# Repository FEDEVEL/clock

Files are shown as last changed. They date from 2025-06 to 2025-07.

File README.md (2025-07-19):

# DESIGN AND BUILD THIS CLOCK BY YOURSELF
Watch a full step-by-step tutorial about how you can build this clock by yourself here: https://youtu.be/bcvq30J4SnQ

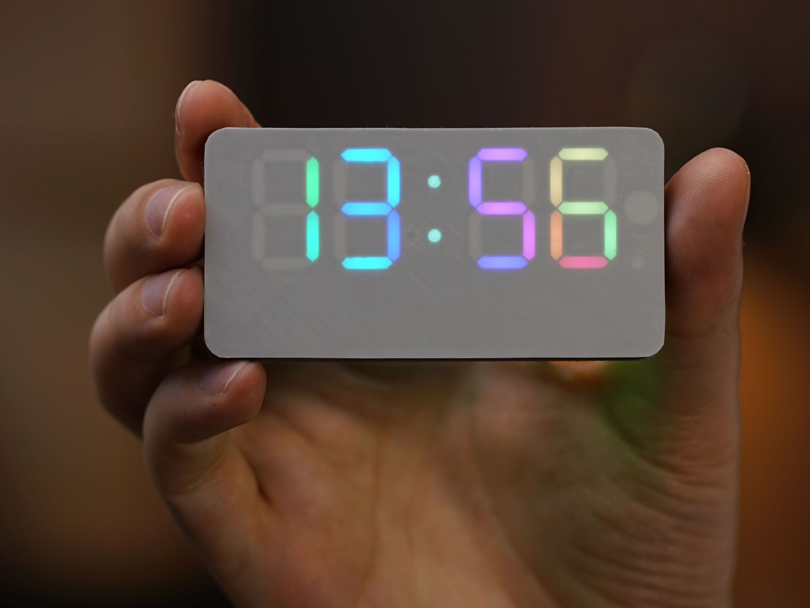
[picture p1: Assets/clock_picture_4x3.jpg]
Clock


# About this Clock Project
I created this clock for everyone who is interested in electronics. Even if you have never designed any electronics before, by following this step-by-step youtube tutorial you will design and manufacture this clock.

Watch and follow the tutorial here: https://youtu.be/bcvq30J4SnQ

# Clock Description
This is a nice clock with big segments and you can set color and intesity of each segment. There are three buttons, buzzer, light sensor and RTC with battery backup. The clock is powered through USB C and has features such current time, timer and stopwatch. Feel free to add your own features!

Why I designed this clock?
- it's a very simple project, so it was fun
- I often need a clock with big display and the right color and intensity when checking time in the middle of the night without my glasses on
- I often need a simple timer or stopwatch for example when cooking

# What is in this github repository
You will find here all the files you need to build this clock.

# Schematic and PCB
If you just would like to open and have a look at the Schematic and PCB, you can do it directly in your browser, here: https://oshwlab.com/robertferanec/clock/

# User Manual (How to use this clock)
The clock has three modes: Clock, Stopwatch and Timer. To switch between the modes press the buttons. The clock has battery backed RTC to keep the time always accurate. A simple web interface can be used to change default settings. I will write more detialed manual if there is interest. 

# License
Clock © 2025 by FEDEVEL is licensed under [Creative Commons Attribution-NonCommercial-ShareAlike 4.0 International](https://creativecommons.org/licenses/by-nc-sa/4.0/?ref=chooser-v1). For commercial use, contact me at info@fedevel.com

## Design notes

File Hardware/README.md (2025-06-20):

# What is here
- EasyEDA source file with Schematic and PCB (this file can be imported to EasyEDA PRO software)
- All the files needed to manufacture and build the clock (inside of Manufacturing directory)

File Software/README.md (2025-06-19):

# What is here
- Circuitpython (file adafruit-circuitpython-raspberry_pi_pico-en_US-9.2.7.uf2)
- Clock firmware source files (inside of RP2040 Files)
- Clock configuration website (RP2040 Files/clock_setup.html)

# To flash the firmware
## Flash this first - Circuitpython
Connect the board to USB and quickly press Reset button twice. The board will appear as RPI-RP2 storage. Copy adafruit-circuitpython-raspberry_pi_pico-en_US-9.2.7.uf2 file there. You need to do this only once.

## Updating the clock firmware
Before this, you need to have Circuitpython running on the clock board already (see the previous step). To update the clock software, folow these steps:
1. Hold USR1 button down and connect the board to USB
1. The board will be mounted as CIRCUITPY storage
1. Copy all the files from RP2040 Files directory to CIRCUITPY storage

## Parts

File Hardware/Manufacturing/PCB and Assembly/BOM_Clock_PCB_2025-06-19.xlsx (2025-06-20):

No. | Quantity | Comment | Designator | Footprint | Value | Manufacturer Part | Manufacturer | Supplier Part | Supplier | Layer
1 | 1 | 2.7kHz | BUZZER1 | BUZ-TH_BD9.0-P4.00-D0.6-FD | 2.7kHz | QMB-09B-03 | 华能 | C96256 | LCSC | B
2 | 4 | 2.2uF | C101,C105,C106,C107 | C0402 | 2.2uF | CL05A225MQ5NSNC | SAMSUNG(三星) | C12530 | LCSC | B
3 | 48 | 100nF | C102,C103,C104,C108,C109,C113,C114,C115,C116,C125,C126,C127,C210,C211,C212,C213,C214,C215,C216,C217,C218,C219,C220,C221,C222,C223,C224,C225,C226,C227,C228,C229,C230,C231,C232,C233,C234,C235,C236,C237,C238,C239,C240,C241,C242,C244,C245,C246 | C0402 | 100nF | CL05B104KO5NNNC | SAMSUNG(三星) | C1525 | LCSC | B
4 | 5 | 1uF | C110,C111,C118,C119,C248 | C0402 | 1uF | CL05A105KA5NQNC | SAMSUNG(三星) | C52923 | LCSC | B
5 | 1 | 47uF | C112 | C1206 | 47uF | CL31A476MPHNNNE | SAMSUNG(三星) | C96123 | LCSC | B
6 | 3 | 15pF | C123,C124,C247 | C0402 | 15pF | CL05C150JB5NNNC | SAMSUNG(三星) | C86285 | LCSC | B
7 | 4 | GG0402052R542P | D101,D102,D103,D104 | D0402-BI |  | GG0402052R542P | Kyocera AVX | C1973257 | LCSC | B
8 | 1 | 1N4148WS | D105 | SOD-323_L1.8-W1.3-LS2.5-RD |  | 1N4148WS | CJ(江苏长电/长晶) | C2128 | LCSC | B
9 | 1 | MC-110LD-L93 | J101 | USB-C-TH_MC-110LD-L93_1 |  | MC-110LD-L93 | HANBO(汉博) | C2962413 | LCSC | B
10 | 31 | SK6812MINI-E | LED201,LED202,LED203,LED204,LED205,LED206,LED207,LED208,LED209,LED210,LED211,LED212,LED213,LED214,LED215,LED216,LED217,LED218,LED219,LED220,LED221,LED222,LED223,LED224,LED225,LED226,LED227,LED228,LED229,LED230,LED231 | LED-SMD_L3.2-W2.8-TR |  | SK6812MINI-E | 欧思科光电 | C5149201 | LCSC | B
11 | 1 | 2N7002BKW,115 | Q1 | SOT-323_L2.0-W1.3-P1.30-LS2.1-BR |  | 2N7002BKW,115 | Nexperia(安世) | C455035 | LCSC | B
12 | 1 | 200Ω | R101 | R0402 | 200Ω | 0402WGF2000TCE | UNI-ROYAL(厚声) | C25087 | LCSC | B
13 | 1 | 100mΩ | R102 | R1206 | 100mΩ | 1206W4F100LT5E | UNI-ROYAL(厚声) | C25334 | LCSC | B
14 | 7 | 27Ω | R109,R111,R125,R126,R130,R132,R134 | R0402 | 27Ω | 0402WGF270JTCE | UNI-ROYAL(厚声) | C25100 | LCSC | B
15 | 2 | 5.1kΩ | R118,R119 | R0402 | 5.1kΩ | 0402WGF5101TCE | UNI-ROYAL(厚声) | C25905 | LCSC | B
16 | 2 | 1kΩ | R121,R124 | R0402 | 1kΩ | 0402WGF1001TCE | UNI-ROYAL(厚声) | C11702 | LCSC | B
17 | 7 | 10kΩ | R123,R129,R131,R133,R136,R137,R138 | R0402 | 10kΩ | 0402WGF1002TCE | UNI-ROYAL(厚声) | C25744 | LCSC | B
18 | 1 | 150Ω | R127 | R1206 | 150Ω | AS0606J0151T5E | UNI-ROYAL(厚声) | C966083 | LCSC | B
19 | 1 | GL5528(10-20) | R135 | RES-TH_L5.1-W4.3-P3.40-D0.5 |  | GL5528(10-20) | JCHL(晶创和立) | C10081 | LCSC | B
20 | 2 | TS-1187A-B-A-B | SW101,SW102 | SW-SMD_4P-L5.1-W5.1-P3.70-LS6.5-TL-2 |  | TS-1187A-B-A-B | XKB Connectivity(中国星坤) | C318884 | LCSC | B
21 | 3 | DTSM-62K-V-T/R | SW103,SW104,SW105 | KEY-SMD_4P-L6.2-W6.2-P4.50-LS9.0 |  | DTSM-62K-V-T/R | 圜达 | C224978 | LCSC | B
22 | 1 | RP2040 | U101 | LQFN-56_L7.0-W7.0-P0.4-EP_1 |  | RP2040 | Raspberry Pi(树莓派) | C2040 | LCSC | B
23 | 1 | LM3940IMP-3.3/NOPB | U102 | SOT-223_L6.5-W3.5-P2.30-LS7.0-BR |  | LM3940IMP-3.3/NOPB | TI(德州仪器) | C140319 | LCSC | B
24 | 2 | SN74LV1T34DBVR | U103,U105 | SOT-23-5_L2.9-W1.6-P0.95-LS2.8-BR |  | SN74LV1T34DBVR | TI(德州仪器) | C100024 | LCSC | B
25 | 1 | W25Q128JVSIQ | U104 | SOIC-8_L5.3-W5.3-P1.27-LS8.0-BL |  | W25Q128JVSIQ | WINBOND(华邦) | C97521 | LCSC | B
26 | 1 | MAX31343ETAY+T | U106 | TDFN-8_L4.0-W3.0-P0.50-BL-EP |  | MAX31343ETAY+T | ADI(亚德诺)/MAXIM(美信) | C7458635 | LCSC | B
27 | 1 | ABM8-272-T3 | Y101 | CRYSTAL-SMD_4P-L3.2-W2.5-BL |  | ABM8-272-T3 | ABRACON | C20625731 | LCSC | B

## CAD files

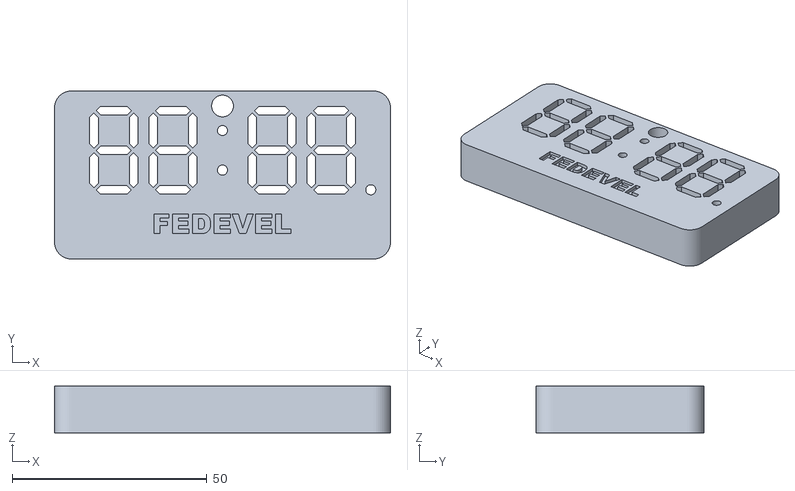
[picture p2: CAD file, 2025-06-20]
Hardware/Manufacturing/Simple Box and Stand/ClockPanel_12mm.stl
86.3 x 43.2 x 12.0

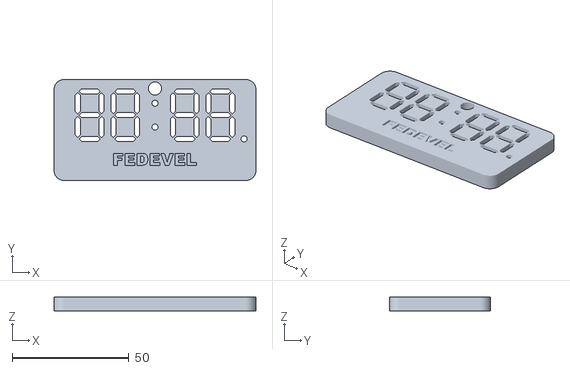
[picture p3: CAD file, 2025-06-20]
Hardware/Manufacturing/Simple Box and Stand/ClockPanel_6mm.stl
86.3 x 43.2 x 6.00

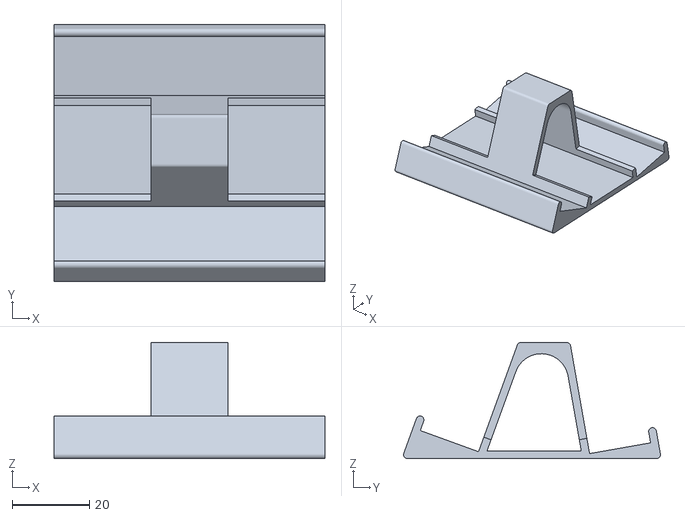
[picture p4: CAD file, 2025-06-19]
Hardware/Manufacturing/Simple Box and Stand/Holder_12mm.stl
70.0 x 66.4 x 30.0

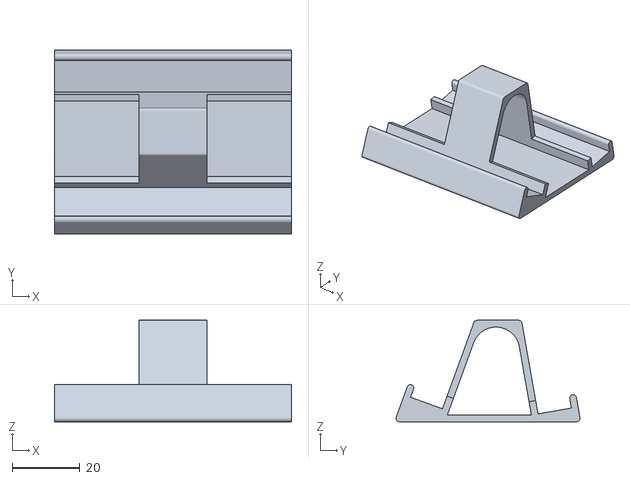
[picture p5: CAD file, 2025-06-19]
Hardware/Manufacturing/Simple Box and Stand/Holder_6mm.stl
70.0 x 54.4 x 30.0

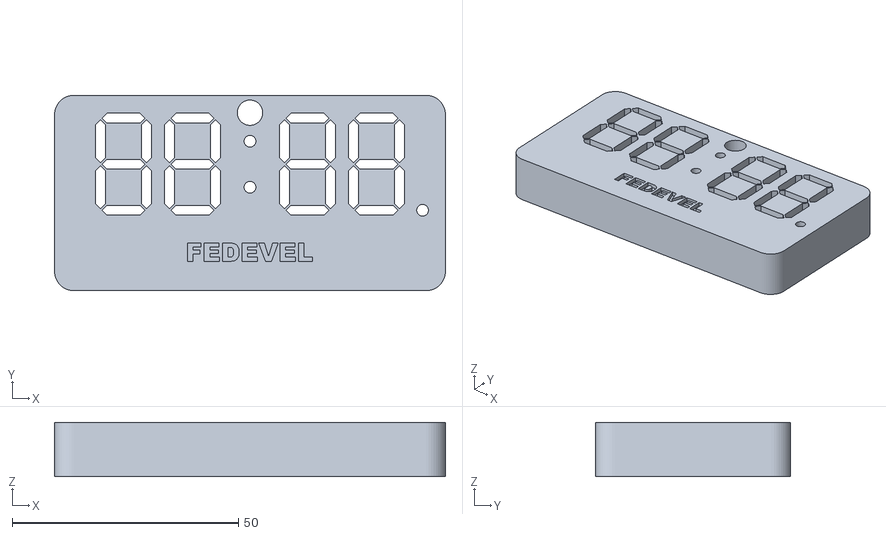
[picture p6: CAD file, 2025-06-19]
Hardware/Manufacturing/Simple Box and Stand/ClockPanel_12mm_print_home.stl
86.3 x 43.2 x 12.0

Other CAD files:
Hardware/Manufacturing/Simple Box and Stand/ClockPanel_6mm_print_home.stl

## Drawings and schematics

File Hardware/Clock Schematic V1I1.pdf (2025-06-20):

# Clock (Page 1/2)

5V to 3V3 | MCU

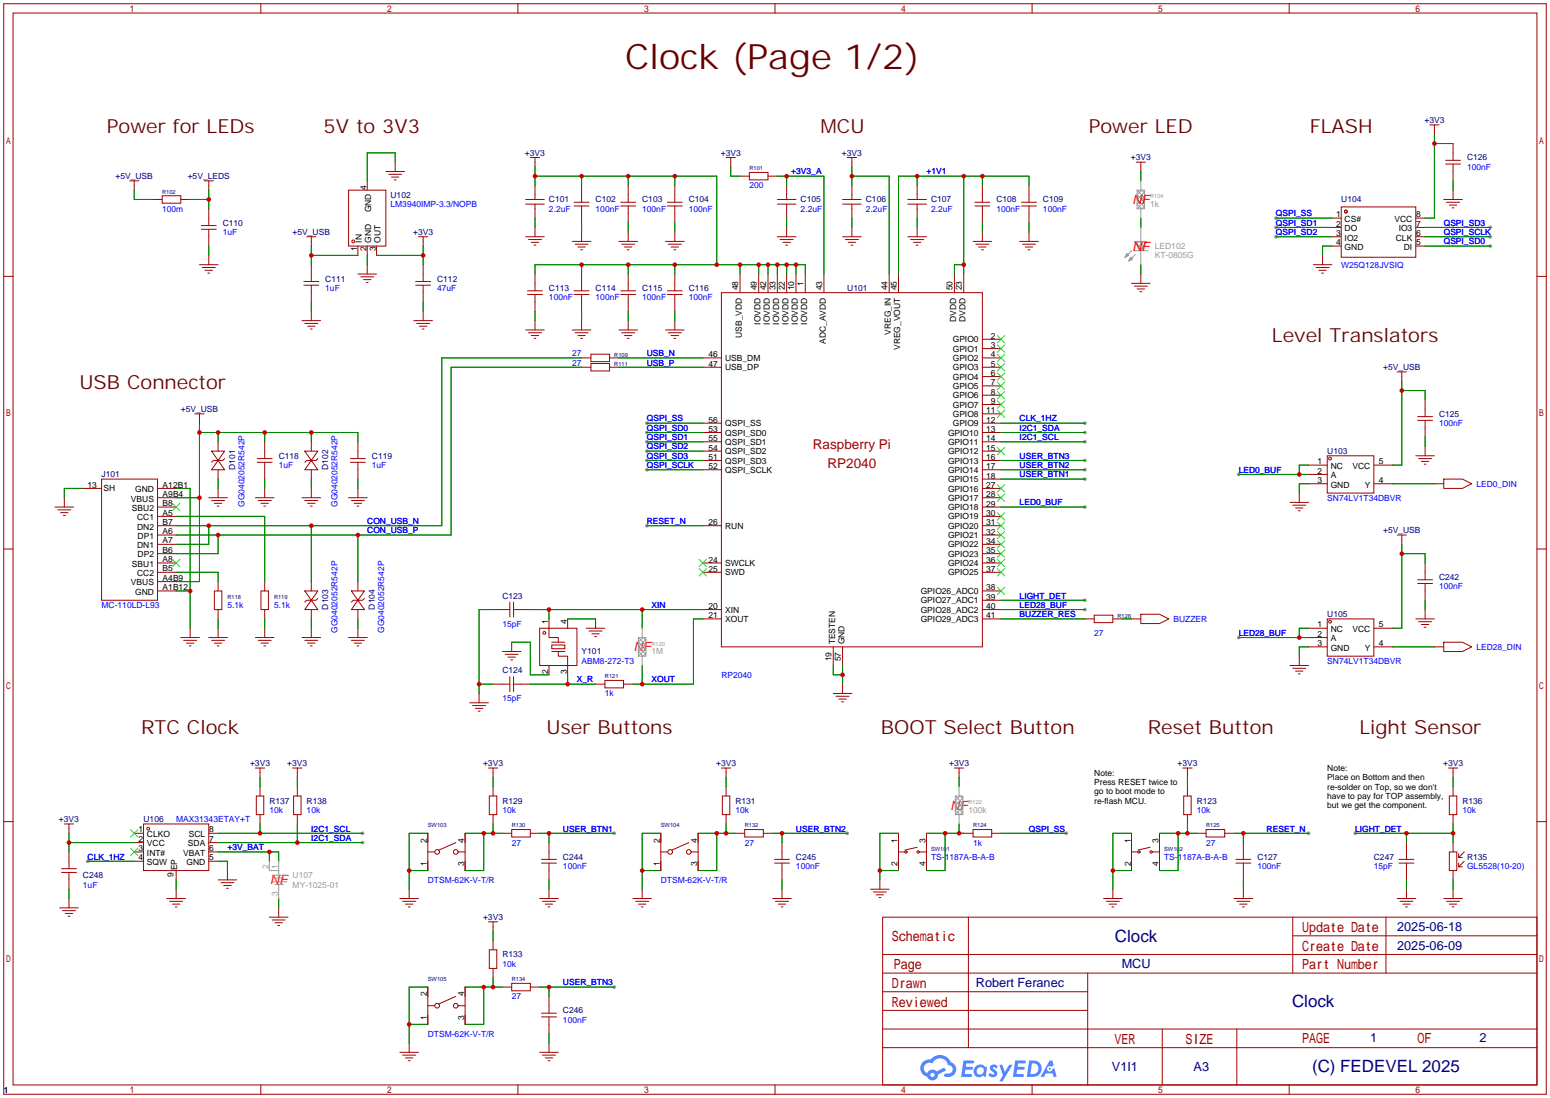
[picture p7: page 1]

Note:
Press RESET twice to
go to boot mode to
re-flash MCU.

Place on Bottom and then
re-solder on Top, so we don't
have to pay for TOP assembly,
but we get the component.

# Clock (Page 2/2)

# SEGMENT LEDs

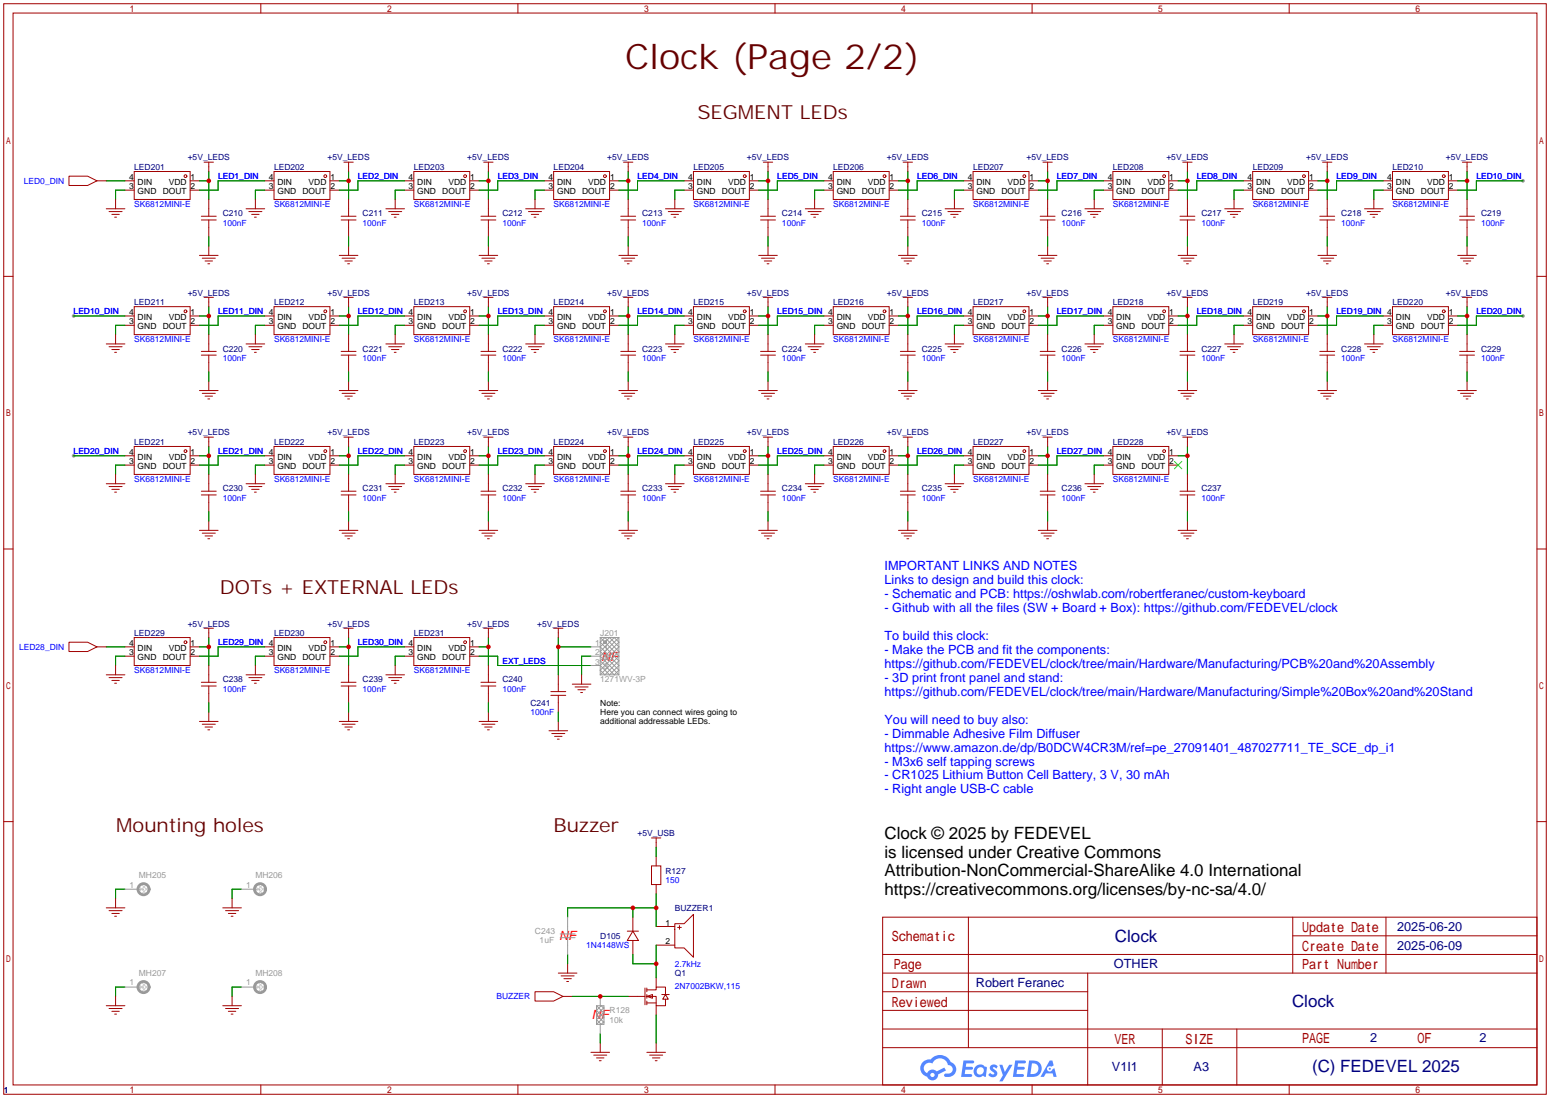
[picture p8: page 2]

IMPORTANT LINKS AND NOTES
Links to design and build this clock:
- Schematic and PCB: https://oshwlab.com/robertferanec/custom-keyboard
- Github with all the files (SW + Board + Box): https://github.com/FEDEVEL/clock
To build this clock:
- Make the PCB and fit the components:
https://github.com/FEDEVEL/clock/tree/main/Hardware/Manufacturing/PCB%20and%20Assembly
- 3D print front panel and stand:
https://github.com/FEDEVEL/clock/tree/main/Hardware/Manufacturing/Simple%20Box%20and%20Stand
You will need to buy also:
- Dimmable Adhesive Film Diffuser
https://www.amazon.de/dp/B0DCW4CR3M/ref=pe_27091401_487027711_TE_SCE_dp_i1
- M3x6 self tapping screws
- CR1025 Lithium Button Cell Battery, 3 V, 30 mAh
- Right angle USB-C cable
Clock © 2025 by FEDEVEL
is licensed under Creative Commons
Attribution-NonCommercial-ShareAlike 4.0 International

Note:
Here you can connect wires going to
additional addressable LEDs.

https://creativecommons.org/licenses/by-nc-sa/4.0/ ¹

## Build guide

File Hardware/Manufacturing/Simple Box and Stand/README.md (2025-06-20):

# Notes
JLC needed 3D models with walls no thinner than 0.8mm so I had to increase the wall thickness between segments. But if you would like to have the wall between segments thinner, you can use the _print_home files (these were my original files and I wanted to keep them).

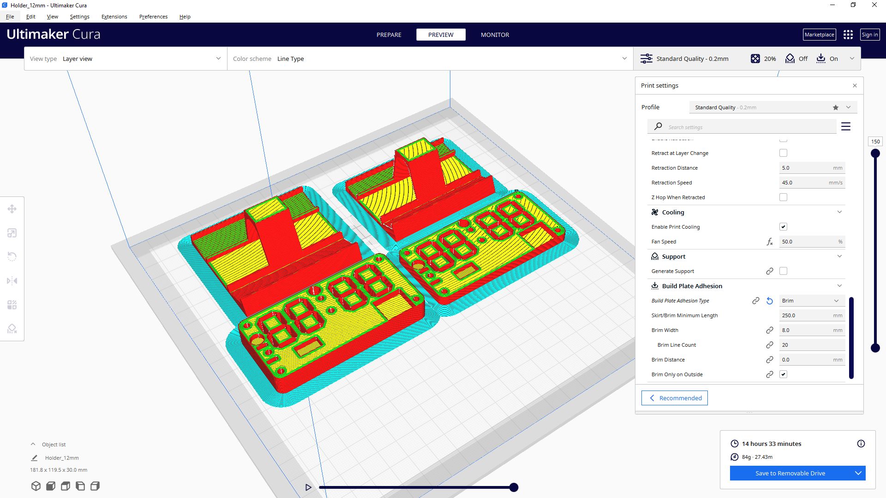
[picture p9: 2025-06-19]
Assets/PrintingSimpleBox.jpg

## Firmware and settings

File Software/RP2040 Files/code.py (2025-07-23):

# code.py # type: ignore
import time
import board
import digitalio
import pwmio
from fdvl_display import Display
from fdvl_rtc import RTC
from fdvl_buttons import Buttons
from fdvl_lightsensor import LightSensor
import usb_cdc
import json


#WATCHDOG
#from microcontroller import watchdog
#from watchdog import WatchDogMode
#watchdog.timeout=30 # Set a timeout of 30 seconds
#watchdog.mode = WatchDogMode.RESET

# Constants
CLOCK_MODE = "CLOCK_MODE"
TIMER_MODE = "TIMER_MODE"
STOPWATCH_MODE = "STOPWATCH_MODE"
STOPWATCH_COUNTING = "STOPWATCH_COUNTING"
STOPWATCH_PAUSED = "STOPWATCH_PAUSED"
REFRESH_INTERVAL = 1.0 / 60  # 60 Hz
SETTLE_PERIOD = 4.0  # Seconds to ignore button events after power-up
RTC_UPDATE_INTERVAL = 1.0  # Seconds between RTC reads
SETTINGS_FILE = "/settings.txt"

# Load settings from settings.txt
def load_settings():
    try:
        with open(SETTINGS_FILE, "r") as f:
            return json.load(f)
    except Exception as e:
        print("Failed to load settings.txt:", e)
        return {}
    
def save_settings():
    try:
        with open(SETTINGS_FILE, "w") as f:
            json.dump(settings, f)
            print("Settings saved.")
    except Exception as e:
        print("Failed to save settings:", e)

def apply_settings():
    # Update buzzer frequency
    global buzzer
    try:
        buzzer.deinit()
    except Exception:
        pass

    try:
        buzzer = pwmio.PWMOut(board.A3, frequency=settings["buzzer_frequency"], duty_cycle=0)
        print("Buzzer reinitialized with new frequency.")
    except Exception as e:
        print("Failed to reinitialize buzzer:", e)

    # Update light sensor thresholds
    try:
        light_sensor.update_thresholds(settings["light_sensor_bright_threshold"], settings["light_sensor_dark_threshold"])
        print("Updated light sensor thresholds.")
    except Exception as e:
        print("Failed to update light sensor:", e)

    # Update light sensor thresholds
    try:
        display.update_settings(settings)
        print("Updated display values.")
    except Exception as e:
        print("Failed to update display:", e)

        


# === Default Config ===
settings = load_settings()


BUZZER_CYCLE_TIME = settings.get("buzzer_beep_duration") + settings.get("buzzer_stop_duration") * 2 + settings.get("buzzer_beep_duration") + settings.get("buzzer_pause_duration")  # s per cycle
print(settings)

#SETUP SERIAL COMMUNICATION
data_serial = usb_cdc.data
data_serial.timeout = 0  # Non-blocking reads

def read_line():
    line = b""
    while True:
        if data_serial.in_waiting > 0:
            char = data_serial.read(1)
            if char == b"\n":
                return line.decode().strip()
            else:
                line += char

def handle_command(line):
    global settings
    try:
        data = json.loads(line)

        cmd = data.get("command")

        if cmd == "set_time":
            rtc.set_time({
                'tm_year': data['tm_year'],
                'tm_mon': data['tm_mon'],
                'tm_mday': data['tm_mday'],
                'tm_hour': data['tm_hour'],
                'tm_min': data['tm_min'],
                'tm_sec': data['tm_sec'],
                'tm_wday': data['tm_wday']
            })
            print("RTC time updated via serial command.")

        elif cmd == "get_settings":
            print("Get settings received")
            # Send current settings back to serial as JSON
            json_data = json.dumps({"settings": settings}) + "\n"
            data_serial.write(json_data.encode("utf-8"))

        else:
            # Assume full settings update
            settings = data
            save_settings()
            print("Settings updated:", settings)
            apply_settings()

    except Exception as e:
        print("JSON parse error:", e)


# Initialize button pins first to stabilize pull-ups
buttons = Buttons(board.GP15, board.GP14, board.GP13)  # BOTTOM, UP, DOWN

# Initialize other peripherals
rtc = RTC(board.GP11, board.GP10)  # SCL=GP11, SDA=GP10
display = Display(board.GP18, board.GP28)
light_sensor = LightSensor(board.GP27, settings.get("light_sensor_bright_threshold"), settings.get("light_sensor_dark_threshold"))  # Light sensor on GPIO27 (ADC1)
buzzer = pwmio.PWMOut(board.A3, frequency=settings.get("buzzer_frequency"), duty_cycle=0)  # Buzzer on GPIO29 (A3)

apply_settings()

# Initialize SWO (CLK_1HZ)
swo = digitalio.DigitalInOut(board.GP9)  # SWO on GPIO9
swo.direction = digitalio.Direction.INPUT
swo.pull = digitalio.Pull.UP

# Get initial time and set if invalid
rtc_time = rtc.get_time()
if rtc_time:
    if rtc_time['tm_year'] < 2025:
        print("Invalid RTC time detected, setting to 2025-05-29 13:21:00")
        rtc.set_time({
            'tm_year': 2025, 'tm_mon': 4, 'tm_mday': 30,
            'tm_hour': 6, 'tm_min': 55, 'tm_sec': 0,
            'tm_wday': 4  # 
        })
        time.sleep(0.1)  # Brief delay to ensure RTC settles
        rtc_time = rtc.get_time()
    print("Initialization complete. Initial time: {:04d}-{:02d}-{:02d} {:02d}:{:02d}:{:02d}".format(
        rtc_time['tm_year'], rtc_time['tm_mon'] + 1, rtc_time['tm_mday'],
        rtc_time['tm_hour'], rtc_time['tm_min'], rtc_time['tm_sec']))
else:
    print("Initialization failed: Could not read RTC")

# State: Default to CLOCK_MODE after pin initialization
mode = CLOCK_MODE
sub_mode = None
last_swo = False
last_swo_change = 0
#last_midnight_check = 0
last_rtc_update = time.monotonic()
effect_active = False
effect_start = 0
buzzer_cycle = 0  # Track buzzer cycle (0 to settings.get("buzzer_max_cycles")-1)
buzzer_state = None  # Track buzzer state (Beep1, Stop1, Beep2, Stop2, Beep3, Pause)
buzzer_state_start = 0  # Track start time of current buzzer state
timer_seconds = 5  # Initial timer value
timer_last_update = 0
stopwatch_seconds = 0  # Stopwatch display value
stopwatch_background_seconds = 0  # Background counting
paused_time = 0  # Time when paused
stopwatch_last_update = 0
start_time = time.monotonic()
settle_confirmed = False
print("Entering mode: {}".format(mode))

# loop_count = 0
# last_time = time.monotonic()

# Main loop
while True:
    #loop_count += 1
    current_time = time.monotonic()

    # Check for new settings via serial
    if data_serial.in_waiting > 0:
        command = read_line()
        handle_command(command)

    # if current_time - last_time >= 1.0:
    #     print("Loop frequency:", loop_count, "Hz")
    #     loop_count = 0
    #     last_time = current_time
    
    # Confirm CLOCK_MODE after settle period (once)
    if not settle_confirmed and current_time - start_time > SETTLE_PERIOD:
        print("Confirmed: Remained in CLOCK_MODE after settle period")
        settle_confirmed = True

    # Update RTC time periodically
    if mode == CLOCK_MODE and current_time - last_rtc_update >= RTC_UPDATE_INTERVAL:
        new_time = rtc.get_time()
        if new_time:
            rtc_time = new_time
        last_rtc_update = current_time

    # Read buttons, ignore events during settle period
    button_event = None
    if current_time - start_time > SETTLE_PERIOD:
        button_event = buttons.get_event()

    # Process button events
    if button_event:
        if mode == CLOCK_MODE:
            if button_event == "DOWN_SHORT":
                mode = TIMER_MODE
                timer_seconds = 5
                timer_last_update = current_time
                print("Entering mode: {}".format(mode))
            elif button_event == "UP_SHORT":
                mode = STOPWATCH_MODE
                sub_mode = STOPWATCH_COUNTING
                stopwatch_seconds = 0
                stopwatch_background_seconds = 0
                paused_time = 0
                stopwatch_last_update = current_time
                print("Entering mode: {} ({})".format(mode, sub_mode))
            elif button_event == "BOTTOM_SHORT":
                effect_active = True
                effect_start = current_time
                buzzer_cycle = 0
                buzzer_state = "Beep1"
                buzzer_state_start = current_time
                buzzer.duty_cycle = 32768  # Start first beep
                print("CLOCK_MODE: Starting snake rainbow effect with buzzer")
        elif mode == TIMER_MODE:
            if button_event == "BOTTOM_SHORT":
                mode = CLOCK_MODE
                print("Entering mode: {}".format(mode))
            elif button_event == "DOWN_SHORT":
                timer_seconds += 5
                print("TIMER_MODE: Added 5 seconds, new time: {} seconds".format(timer_seconds))
            elif button_event == "UP_SHORT":
                timer_seconds += 60
                print("TIMER_MODE: Added 1 minute, new time: {} seconds".format(timer_seconds))
        elif mode == STOPWATCH_MODE:
            if button_event == "BOTTOM_SHORT":
                mode = CLOCK_MODE
                print("Entering mode: {}".format(mode))
            elif button_event == "UP_SHORT":
                if sub_mode == STOPWATCH_COUNTING:
                    stopwatch_seconds = 0
                    stopwatch_background_seconds = 0
                    stopwatch_last_update = current_time
                    print("STOPWATCH_MODE: Reset to 00:00, mode: {}".format(sub_mode))
                elif sub_mode == STOPWATCH_PAUSED:
                    sub_mode = STOPWATCH_COUNTING
                    stopwatch_seconds = stopwatch_background_seconds
                    paused_time = 0
                    print("STOPWATCH_MODE: Resumed from background time, mode: {}".format(sub_mode))
            elif button_event == "DOWN_SHORT":
                if sub_mode == STOPWATCH_COUNTING:
                    sub_mode = STOPWATCH_PAUSED
                    paused_time = stopwatch_seconds
                    print("STOPWATCH_MODE: Paused at {:02d}:{:02d}, mode: {}".format(
                        paused_time // 60, paused_time % 60, sub_mode))
                elif sub_mode == STOPWATCH_PAUSED:
                    sub_mode = STOPWATCH_COUNTING
                    stopwatch_seconds = paused_time
                    print("STOPWATCH_MODE: Resumed from paused time, mode: {}".format(sub_mode))
    
    # Handle buzzer pattern during rainbow effect
    if effect_active:
        elapsed = current_time - buzzer_state_start
        cycle_elapsed = current_time - effect_start - (buzzer_cycle * BUZZER_CYCLE_TIME)
        
        if buzzer_cycle < settings.get("buzzer_max_cycles"):
            if buzzer_state == "Beep1" and elapsed >= settings.get("buzzer_beep_duration"):
                buzzer.duty_cycle = 0
                buzzer_state = "Stop1"
                buzzer_state_start = current_time
            elif buzzer_state == "Stop1" and elapsed >= settings.get("buzzer_stop_duration"):
                buzzer.duty_cycle = 32768
                buzzer_state = "Beep2"
                buzzer_state_start = current_time
            elif buzzer_state == "Beep2" and elapsed >= settings.get("buzzer_beep_duration"):
                buzzer.duty_cycle = 0
                buzzer_state = "Stop2"
                buzzer_state_start = current_time
            elif buzzer_state == "Stop2" and elapsed >= settings.get("buzzer_stop_duration"):
                buzzer.duty_cycle = 32768
                buzzer_state = "Beep3"
                buzzer_state_start = current_time
            elif buzzer_state == "Beep3" and elapsed >= settings.get("buzzer_beep_duration"):
                buzzer.duty_cycle = 0
                buzzer_state = "Pause"
                buzzer_state_start = current_time
            elif buzzer_state == "Pause" and elapsed >= settings.get("buzzer_pause_duration"):
                buzzer_cycle += 1
                if buzzer_cycle < settings.get("buzzer_max_cycles"):
                    buzzer.duty_cycle = 32768
                    buzzer_state = "Beep1"
                    buzzer_state_start = current_time
        
        # End effect after 5 seconds
        if current_time - effect_start >= 5:
            effect_active = False
            buzzer.duty_cycle = 0  # Ensure buzzer is off
            print("CLOCK_MODE: Snake rainbow effect ended")
    
    # # Check for midnight (once per minute)
    # if current_time - last_midnight_check >= 60:
    #     if rtc_time and rtc_time['tm_hour'] == 0 and rtc_time['tm_min'] == 0:
    #         new_time = rtc.get_time()
    #         if new_time:
    #             rtc_time = new_time
    #             print("Midnight sync: {:04d}-{:02d}-{:02d} {:02d}:{:02d}:{:02d}".format(
    #                 rtc_time['tm_year'], rtc_time['tm_mon'] + 1, rtc_time['tm_mday'],
    #                 rtc_time['tm_hour'], rtc_time['tm_min'], rtc_time['tm_sec']))
    #     last_midnight_check = current_time
    
    # Synchronize timer and stopwatch with SWO
    swo_state = swo.value
    if swo_state and not last_swo and current_time - last_swo_change > 0.1:
        if mode == TIMER_MODE:
            timer_seconds -= 1
            timer_last_update = current_time
            if timer_seconds == 0:
                print("TIMER_MODE: Timer reached zero")
            elif timer_seconds == -1:
                print("TIMER_MODE: Timer entered negative time")
        elif mode == STOPWATCH_MODE:
            stopwatch_background_seconds += 1
            if sub_mode == STOPWATCH_COUNTING:
                stopwatch_seconds += 1
            stopwatch_last_update = current_time
    
    # Update SWO state
    if swo_state != last_swo:
        last_swo = swo_state
        last_swo_change = current_time

    brightness = light_sensor.get_brightness()
    # Update display
    if mode == CLOCK_MODE:
        if effect_active:
            display.show_time_with_effect(rtc_time, swo_state, current_time - effect_start)
        else:
            display.show_time(rtc_time, swo_state, brightness)
    elif mode == TIMER_MODE:
        if buttons.is_bottom_held():
            display.show_time(rtc_time, swo_state, brightness)
            print("TIMER_MODE: Showing clock time during BOTTOM_BTN hold")
        else:
            display.show_timer(timer_seconds, swo_state, brightness)
    elif mode == STOPWATCH_MODE:
        if buttons.is_bottom_held():
            display.show_time(rtc_time, swo_state, brightness)
            print("STOPWATCH_MODE: Showing clock time during BOTTOM_BTN hold")
        else:
            display_seconds = paused_time if sub_mode == STOPWATCH_PAUSED else stopwatch_seconds
            display.show_stopwatch(display_seconds, swo_state, brightness)

    #watchdog.feed()
    time.sleep(REFRESH_INTERVAL)

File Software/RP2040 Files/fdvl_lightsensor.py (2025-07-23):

# fdvl_lightsensor.py
import analogio # type: ignore

class LightSensor:
    # Brightness thresholds
    BRIGHT_THRESHOLD = 30000
    DARK_THRESHOLD = 49000

    def __init__(self, adc_pin, light_sensor_bright_threshold, light_sensor_dark_threshold):
        self.adc = analogio.AnalogIn(adc_pin)
        self.BRIGHT_THRESHOLD = light_sensor_bright_threshold
        self.DARK_THRESHOLD = light_sensor_dark_threshold

    def update_thresholds(self, bright, dark):
        self.BRIGHT_THRESHOLD = bright
        self.DARK_THRESHOLD = dark

    def get_brightness(self):
        """Determine brightness mode based on light sensor."""
        value = self.adc.value
        if value < self.BRIGHT_THRESHOLD:
            return "BRIGHT"
        elif value > self.DARK_THRESHOLD:
            return "DARK"
        return "NORMAL"

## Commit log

2025-06-19 3d models added
    [ClockPanel_12mm.stl, ClockPanel_6mm.stl, Holder_12mm.stl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]
2025-06-20 Updates after sent to production
    [BOM_Clock_PCB_2025-06-19.xlsx, ClockPanel_12mm.stl, ClockPanel_12mm_print_home.stl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]
